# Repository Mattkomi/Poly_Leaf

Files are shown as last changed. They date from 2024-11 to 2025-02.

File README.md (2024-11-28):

# Poly_Leaf
PFE 2024-2025 Polytech SIR, projet Visio
Ce projet vise à développer un système de Stream Deck permettant de centraliser et d'optimiser la gestion des équipements situés dans des salles spécifiques. 
L'objectif est de créer un dispositif ergonomique et intuitif regroupant toutes les connexions HDMI, RJ45, et USB des différents équipements dans un système unifié, 
tout en offrant des fonctionnalités avancées comme la création de macros personnalisées.

Le système est conçu pour :

Simplifier la gestion des équipements grâce à une interface centralisée.
Automatiser des tâches fréquentes, comme l'affichage des participants sur l'écran de retour ou le lancement d'applications utilisées régulièrement.
Reproduire, tout en innovant, les fonctionnalités de l'interface StarLeaf.
Ce projet a été réalisé dans le cadre du PFE VISIO de la filière Polytech SIR par :

Vincent Goossens
Matthieu Komisarek

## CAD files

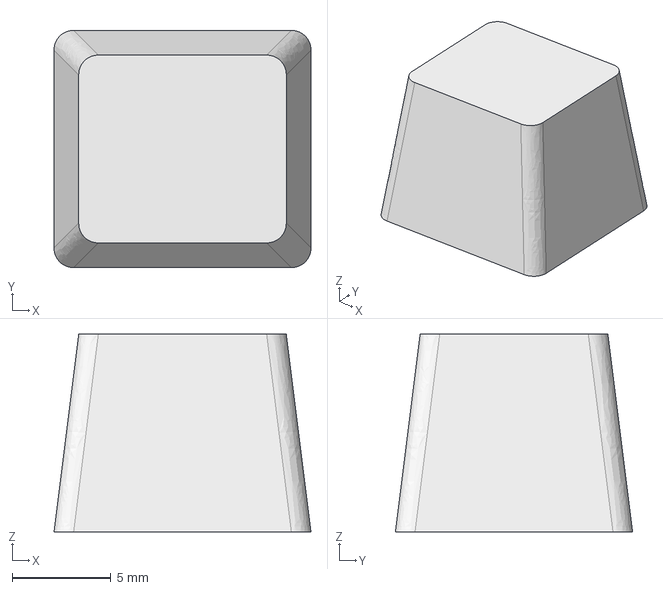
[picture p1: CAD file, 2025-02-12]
CAO/Capuchon.step
13.0 x 12.0 x 10.0 mm

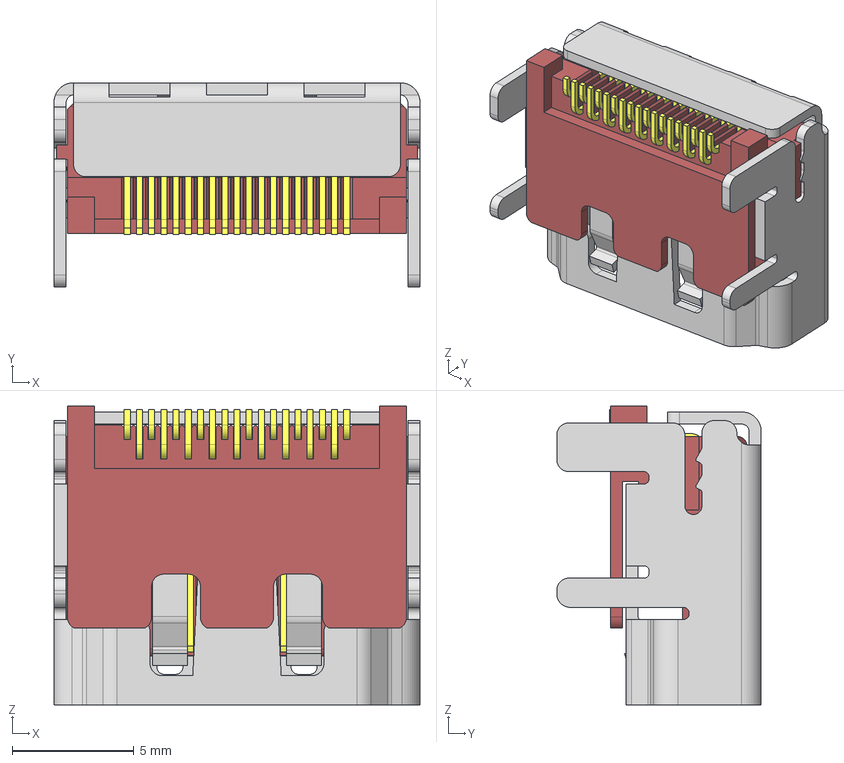
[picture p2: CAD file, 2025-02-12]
PCB_controleur/CAO/HDMR-19-01-S-SM-TR.step
15.0 x 8.38 x 12.2 mm
HDMR-19-01-S-SM-TR_b
HDMR-19-01-S-SM-TR_s
HDMR-19-01-S-SM-TR_p

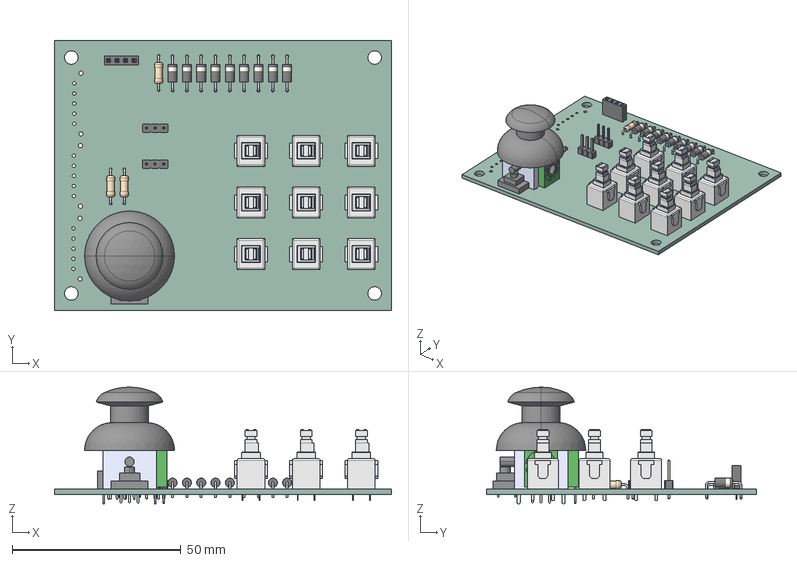
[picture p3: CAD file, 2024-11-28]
PCB_panel/CAO/PCB_panel.step
100.0 x 80.0 x 34.7 mm
D_A-405_P10.16mm_Horizontal x 9
COM-09032
PinHeader_1x03_P254mm_Vertical x 2
PinSocket_1x04_P254mm_Vertical
R_Axial_DIN0207_L63mm_D25mm_P1016mm_Horizontal x 3
PCB_panel PCB

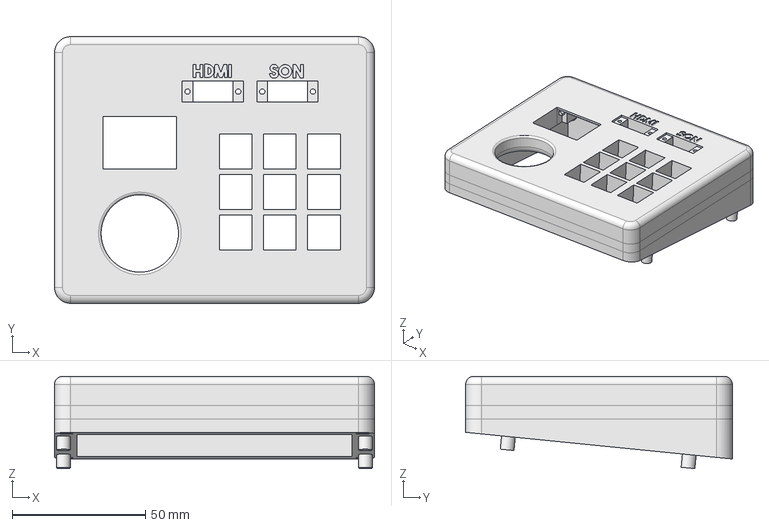
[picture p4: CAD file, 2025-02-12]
CAO/Haut.step
120.0 x 100.0 x 34.6 mm

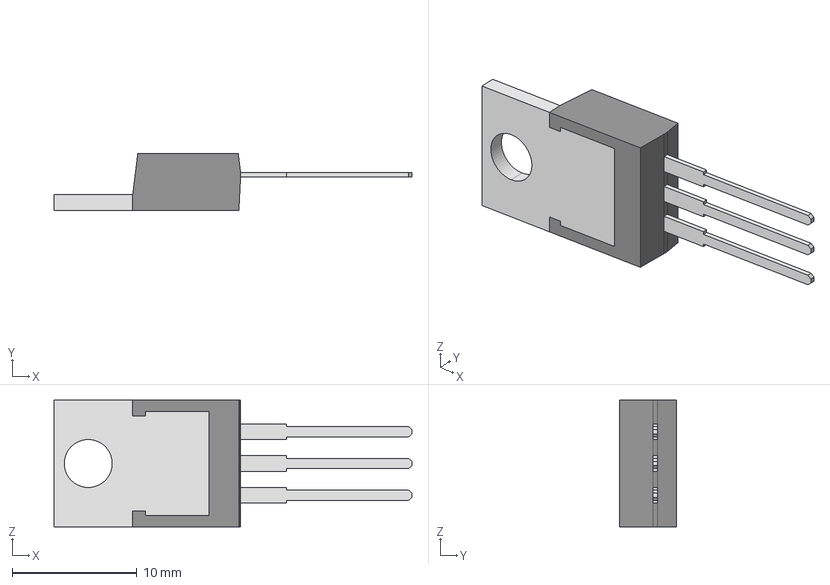
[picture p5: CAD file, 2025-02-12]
PCB_controleur/CAO/NDE0003B.stp
28.7 x 4.57 x 10.2 mm
T03B_BODY
T03B_LEAD x 3
T03B_HS

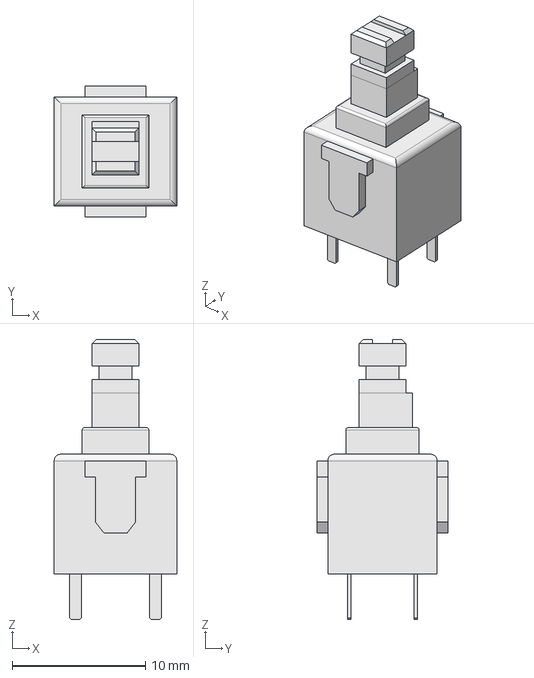
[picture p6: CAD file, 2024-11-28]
PCB_panel/CAO/ToucheF-Body.step
9.20 x 9.80 x 21.0 mm

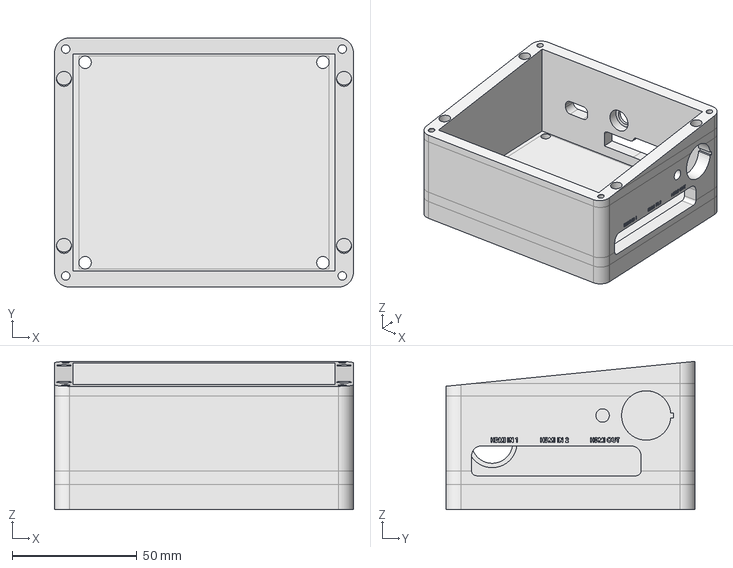
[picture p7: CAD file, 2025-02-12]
CAO/Bas.step
120.0 x 100.0 x 59.5 mm

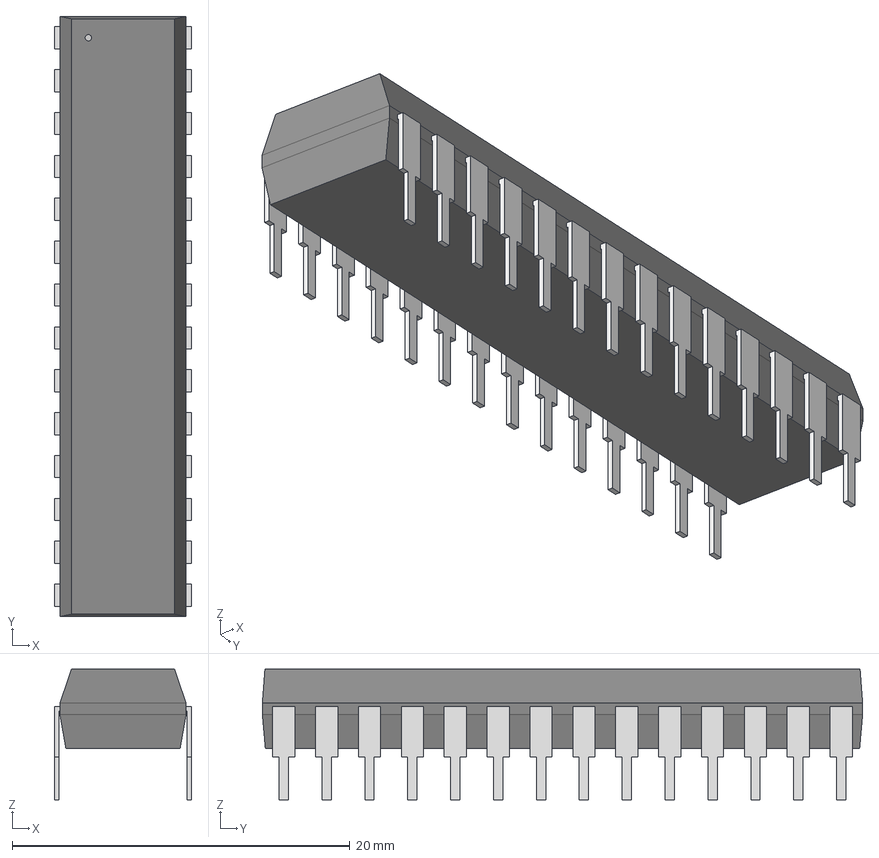
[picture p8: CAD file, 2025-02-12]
PCB_controleur/CAO/SPDIP28_300MC_MCH.step
8.12 x 35.6 x 7.75 mm

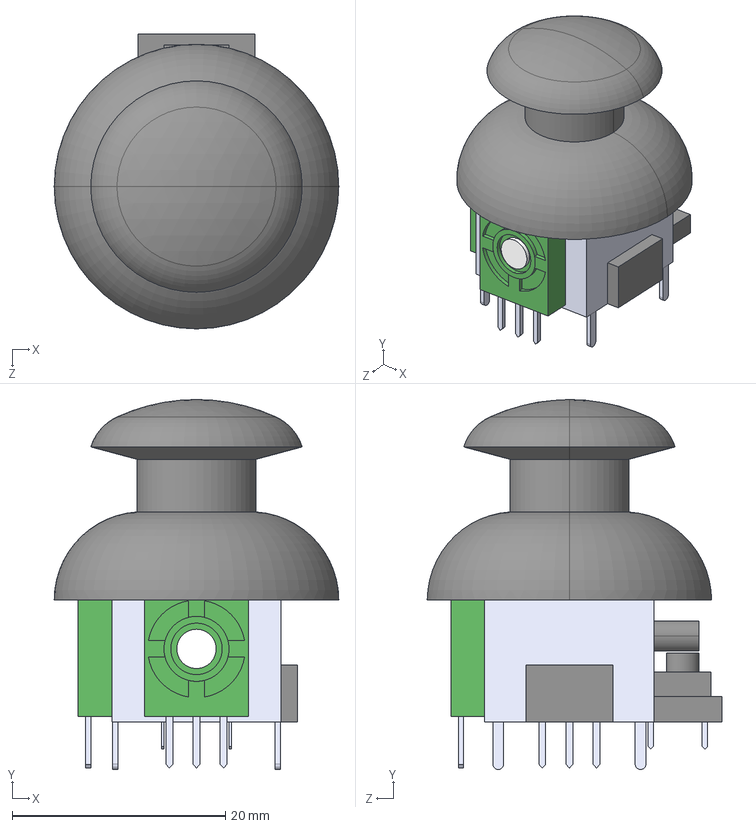
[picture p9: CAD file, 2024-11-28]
PCB_panel/CAO/COM-09032.step
26.7 x 34.7 x 27.6 mm

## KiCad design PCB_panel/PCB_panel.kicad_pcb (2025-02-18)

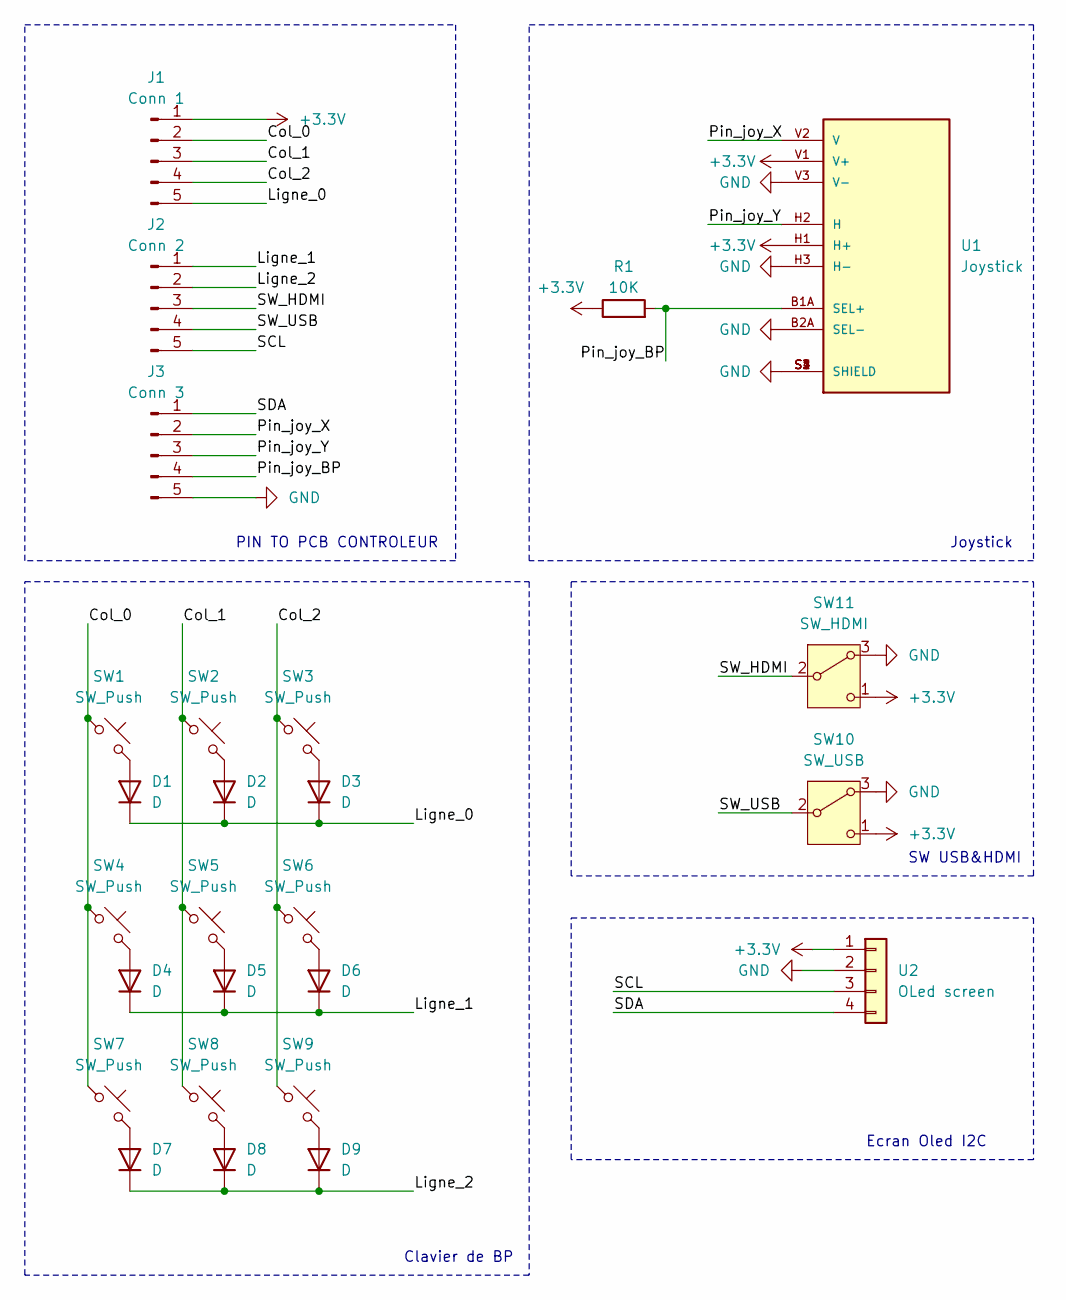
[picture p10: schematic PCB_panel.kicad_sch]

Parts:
D1, D2, D3, D4, D5, D6, D7, D8, D9: D; D_A-405_P10.16mm_Horizontal
J1: Conn 1; Molex_Micro-Fit_3.0_43650-0515_1x05_P3.00mm_Vertical
J2: Conn 2; Molex_Micro-Fit_3.0_43650-0515_1x05_P3.00mm_Vertical
J3: Conn 3; Molex_Micro-Fit_3.0_43650-0515_1x05_P3.00mm_Vertical
R1: 10K; R_Axial_DIN0207_L6.3mm_D2.5mm_P10.16mm_Horizontal
SW1, SW2, SW3, SW4, SW5, SW6, SW7, SW8, SW9: SW_Push; PVA1 OA H1 1.2N V2
SW10: SW_USB; PinHeader_1x03_P2.54mm_Vertical
SW11: SW_HDMI; PinHeader_1x03_P2.54mm_Vertical
U1: Joystick; XDCR_COM-09032; PARTREV N/A
U2: OLed screen; PinSocket_1x04_P2.54mm_Vertical

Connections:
+3.3V: J1.1, R1.1, SW10.1 (C), SW11.1 (C), U1.H1 (H+), U1.V1 (V+), U2.1
/Col_0: J1.2, SW1.1, SW4.1, SW7.1
/Col_1: J1.3, SW2.1, SW5.1, SW8.1
/Col_2: J1.4, SW3.1, SW6.1, SW9.1
/Ligne_0: D1.1 (K), D2.1 (K), D3.1 (K), J1.5
/Ligne_1: D4.1 (K), D5.1 (K), D6.1 (K), J2.1
/Ligne_2: D7.1 (K), D8.1 (K), D9.1 (K), J2.2
/Pin_joy_BP: J3.4, R1.2, U1.B1A (SEL+)
/Pin_joy_X: J3.2, U1.V2 (V)
/Pin_joy_Y: J3.3, U1.H2 (H)
/SCL: J2.5, U2.3
/SDA: J3.1, U2.4
/SW_HDMI: J2.3, SW11.2 (B)
/SW_USB: J2.4, SW10.2 (B)
GND: J3.5, SW10.3 (A), SW11.3 (A), U1.B2A (SEL-), U1.H3 (H-), U1.S1 (SHIELD), U1.S2 (SHIELD), U1.S3 (SHIELD), U1.S4 (SHIELD), U1.V3 (V-), U2.2
unnamed: D1.2 (A), SW1.2
unnamed: D2.2 (A), SW2.2
unnamed: D3.2 (A), SW3.2
unnamed: D4.2 (A), SW4.2
unnamed: D5.2 (A), SW5.2
unnamed: D6.2 (A), SW6.2
unnamed: D7.2 (A), SW7.2
unnamed: D8.2 (A), SW8.2
unnamed: D9.2 (A), SW9.2

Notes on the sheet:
Ecran Oled I2C
SW USB&HDMI
Joystick
PIN TO PCB CONTROLEUR
Clavier de BP

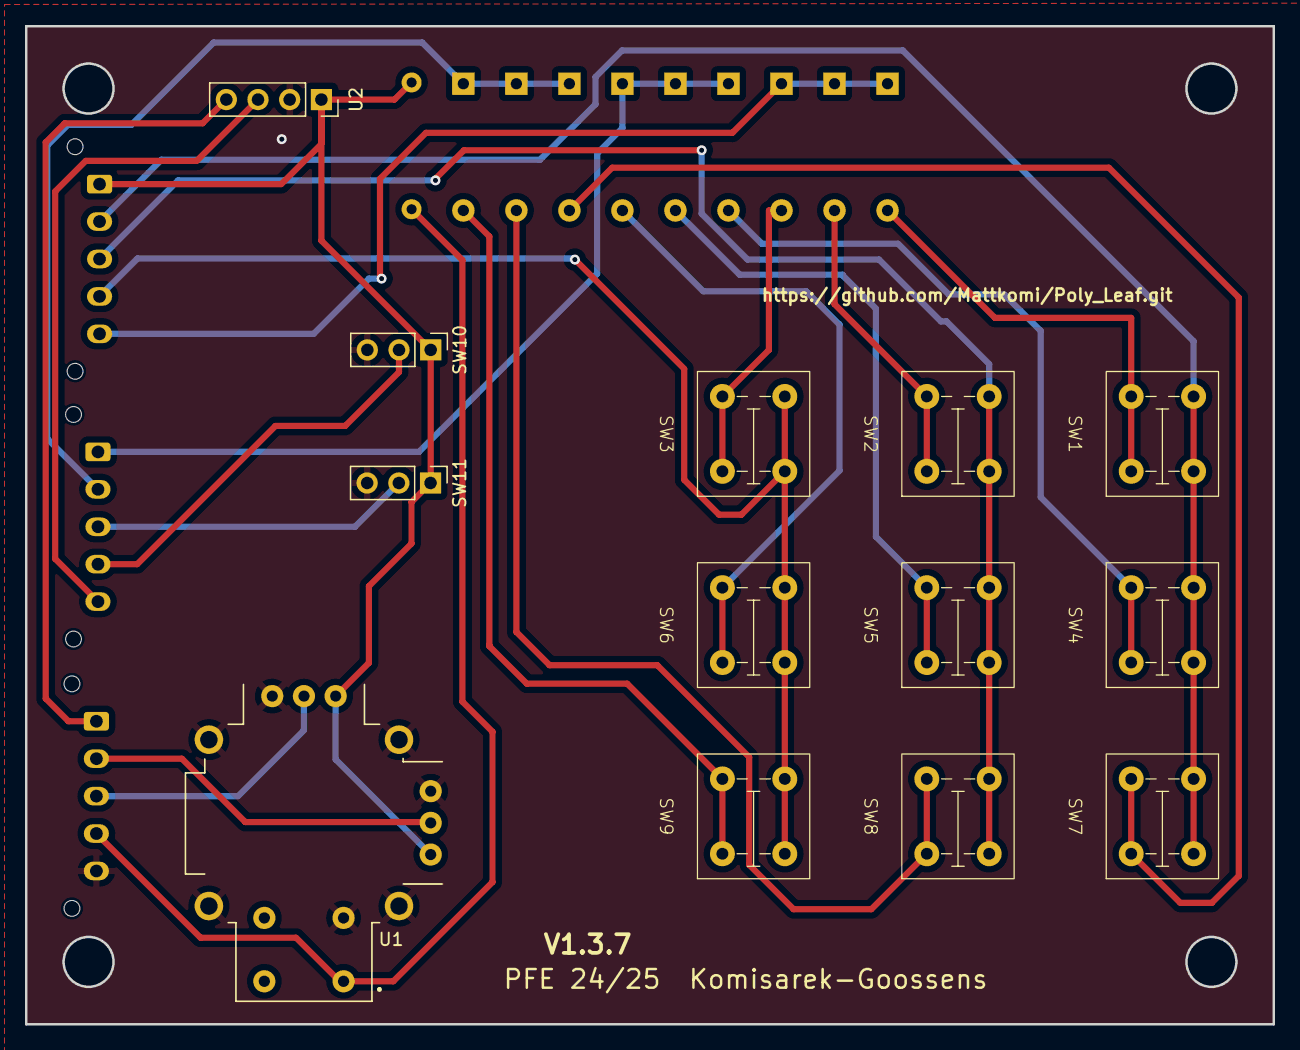
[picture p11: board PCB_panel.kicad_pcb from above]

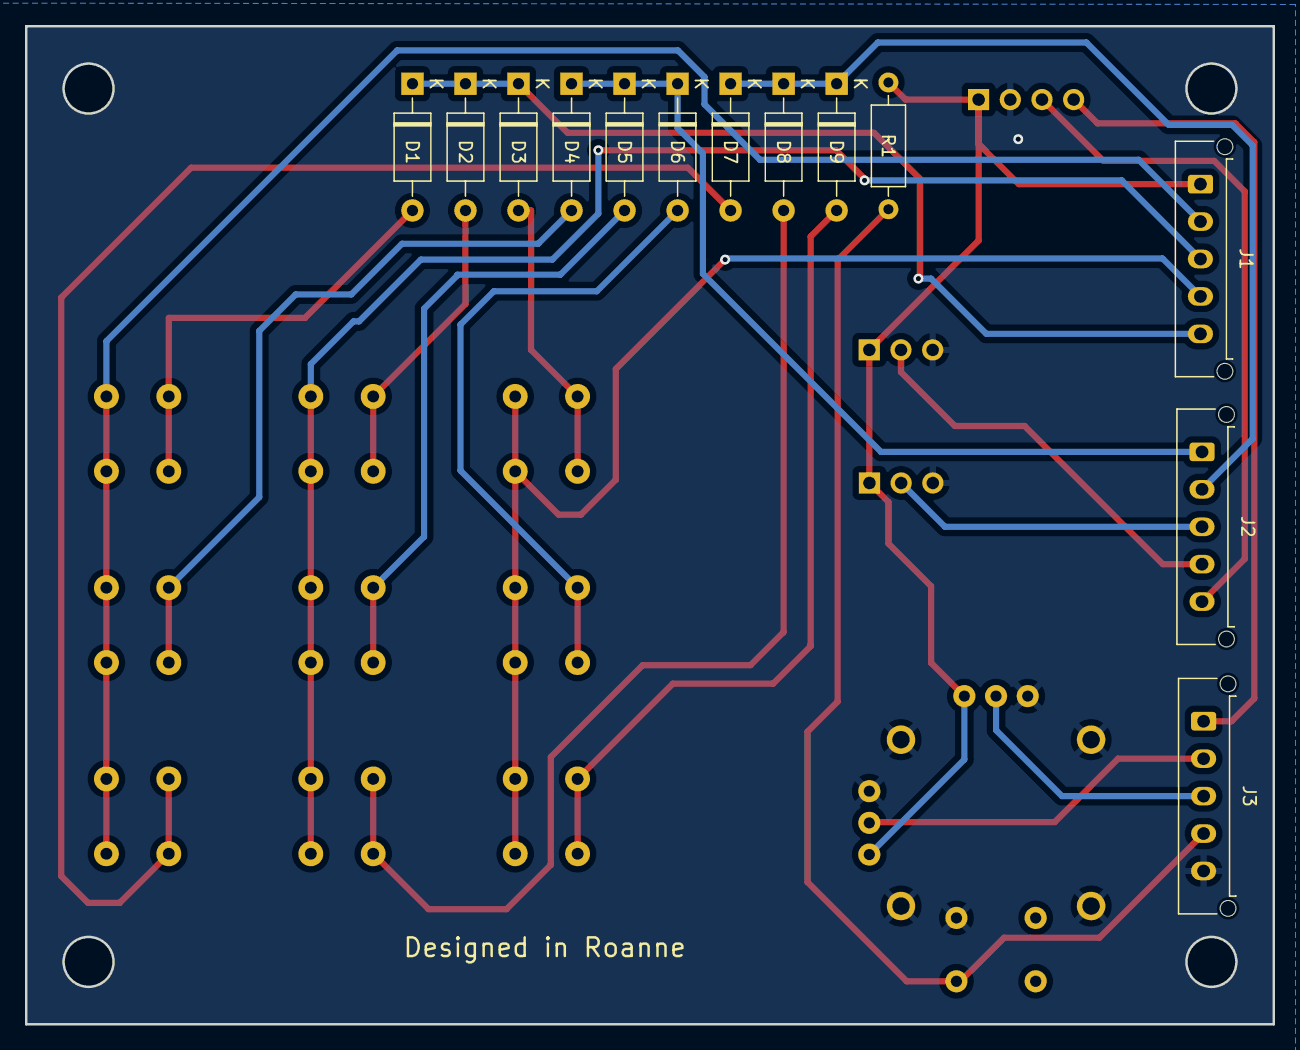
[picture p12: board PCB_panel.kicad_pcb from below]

Board: 2 copper layers, 100.0 x 80.0 mm, 26 parts (13 on the bottom side), 24 nets.

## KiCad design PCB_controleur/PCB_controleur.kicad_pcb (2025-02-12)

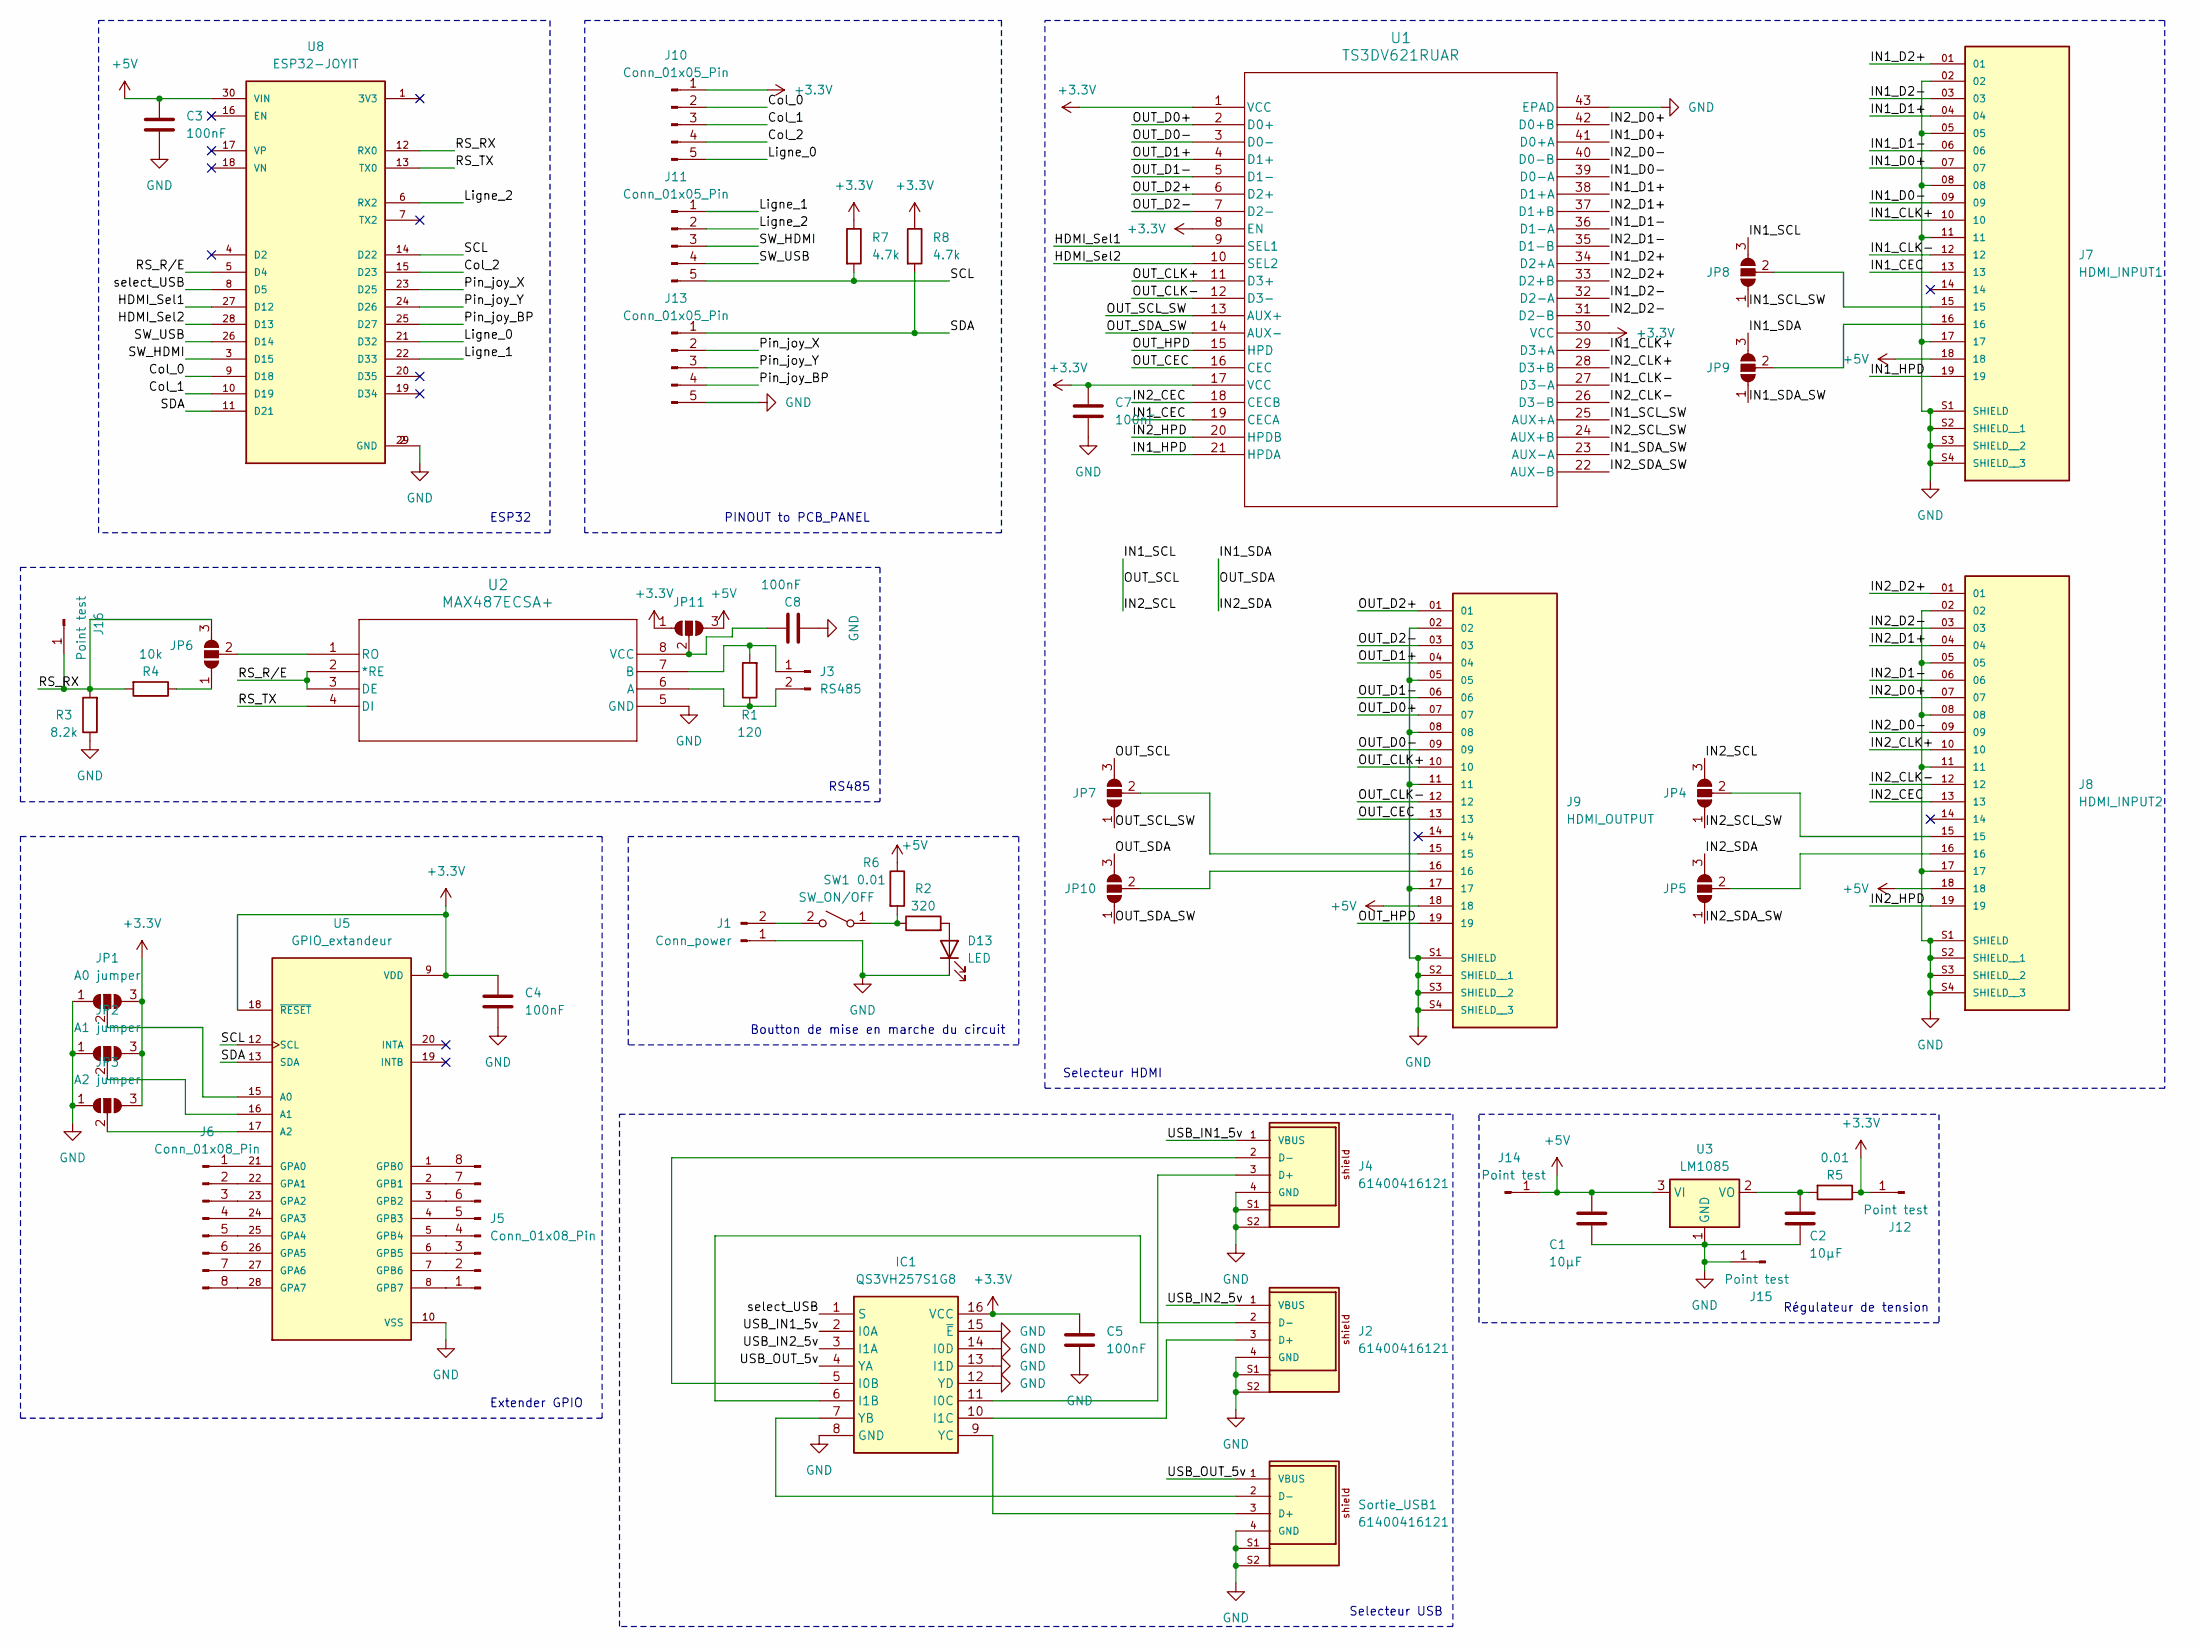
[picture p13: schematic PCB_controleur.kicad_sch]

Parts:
C1, C2: 10µF; CP_Radial_D5.0mm_P2.50mm
C3, C4, C5, C7, C8: 100nF; CAPC2012X135N
D13: LED; LED_D5.0mm
IC1: QS3VH257S1G8; SOIC127P600X175-16N; Manufacturer_Part_Number QS3VH257S1G8
J1: Conn_power; TerminalBlock_bornier-2_P5.08mm
J2, J4: 61400416121; PART-NUMBER 61400416121
J3: RS485; TerminalBlock_bornier-2_P5.08mm
J5, J6: Conn_01x08_Pin; PinHeader_1x08_P2.54mm_Vertical
J7: HDMI_INPUT1; SAMTEC_HDMR-19-01-S-SM-TR; PARTREV H
J8: HDMI_INPUT2; SAMTEC_HDMR-19-01-S-SM-TR; PARTREV H
J9: HDMI_OUTPUT; SAMTEC_HDMR-19-01-S-SM-TR; PARTREV H
J10, J11, J13: Conn_01x05_Pin; Molex_Micro-Fit_3.0_43650-0515_1x05_P3.00mm_Vertical
J12, J14, J15, J16: Point test; PinHeader_1x01_P2.00mm_Vertical
JP1: A0 jumper; SolderJumper-3_P1.3mm_Open_Pad1.0x1.5mm
JP2: A1 jumper; SolderJumper-3_P1.3mm_Open_Pad1.0x1.5mm
JP3: A2 jumper; SolderJumper-3_P1.3mm_Open_Pad1.0x1.5mm
JP4, JP5, JP6, JP7, JP8, JP9, JP10, JP11: SolderJumper_3_Open; SolderJumper-3_P1.3mm_Open_RoundedPad1.0x1.5mm_NumberLabels
R1: 120; R_Axial_DIN0207_L6.3mm_D2.5mm_P10.16mm_Horizontal
R2: 320; R_Axial_DIN0207_L6.3mm_D2.5mm_P10.16mm_Horizontal
R3: 8.2k; R_Axial_DIN0207_L6.3mm_D2.5mm_P10.16mm_Horizontal
R4: 10k; R_Axial_DIN0207_L6.3mm_D2.5mm_P10.16mm_Horizontal
R5, R6: 0.01; WSHM28181L000FEA
R7, R8: 4.7k; R_Axial_DIN0207_L6.3mm_D2.5mm_P10.16mm_Horizontal
SW1: SW_ON/OFF; JST_EH_B2B-EH-A_1x02_P2.50mm_Vertical
Sortie_USB1: 61400416121; 62900416021; PART-NUMBER 61400416121
U1: TS3DV621RUAR; RUA42_7P55X2P05_TEX
U2: MAX487ECSA+; 21-0041B_8_MXM
U3: LM1085; TO-220-3_Vertical
U5: GPIO_extandeur; SPDIP28_300MC_MCH; PARTREV C
U8: ESP32-JOYIT; MODULE_ESP32_DEVKIT_JOYIT; PARTREV N/A

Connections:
+3.3V: C4.1, C5.1, C7.1, IC1.16 (VCC), J10.1, J12.1, JP1.3 (B), JP2.3 (B), JP3.3 (B), JP11.1 (A), R5.1, R7.1, R8.1, U1.1 (VCC), U1.8 (EN), U1.17 (VCC), U1.30 (VCC), U5.9 (VDD), U5.18 (~RESET)
+5V: C1.1, C3.1, J7.18, J8.18, J9.18, J14.1, JP11.3 (B), R6.1, U3.3 (VI), U8.30 (VIN)
/Col_0: J10.2, U8.9 (D18)
/Col_1: J10.3, U8.10 (D19)
/Col_2: J10.4, U8.15 (D23)
/HDMI_Sel1: U1.9 (SEL1), U8.27 (D12)
/HDMI_Sel2: U1.10 (SEL2), U8.28 (D13)
/IN1_CEC: J7.13, U1.19 (CECA)
/IN1_CLK+: J7.10, U1.29 (D3+A)
/IN1_CLK-: J7.12, U1.27 (D3-A)
/IN1_D0+: J7.07, U1.41 (D0+A)
/IN1_D0-: J7.09, U1.39 (D0-A)
/IN1_D1+: J7.04, U1.38 (D1+A)
/IN1_D1-: J7.06, U1.36 (D1-A)
/IN1_D2+: J7.01, U1.34 (D2+A)
/IN1_D2-: J7.03, U1.32 (D2-A)
/IN1_HPD: J7.19, U1.21 (HPDA)
/IN1_SCL: JP4.3 (B), JP7.3 (B), JP8.3 (B)
/IN1_SCL_SW: JP8.1 (A), U1.25 (AUX+A)
/IN1_SDA: JP5.3 (B), JP9.3 (B), JP10.3 (B)
/IN1_SDA_SW: JP9.1 (A), U1.23 (AUX-A)
/IN2_CEC: J8.13, U1.18 (CECB)
/IN2_CLK+: J8.10, U1.28 (D3+B)
/IN2_CLK-: J8.12, U1.26 (D3-B)
/IN2_D0+: J8.07, U1.42 (D0+B)
/IN2_D0-: J8.09, U1.40 (D0-B)
/IN2_D1+: J8.04, U1.37 (D1+B)
/IN2_D1-: J8.06, U1.35 (D1-B)
/IN2_D2+: J8.01, U1.33 (D2+B)
/IN2_D2-: J8.03, U1.31 (D2-B)
/IN2_HPD: J8.19, U1.20 (HPDB)
/IN2_SCL_SW: JP4.1 (A), U1.24 (AUX+B)
/IN2_SDA_SW: JP5.1 (A), U1.22 (AUX-B)
/Ligne_0: J10.5, U8.21 (D32)
/Ligne_1: J11.1, U8.22 (D33)
/Ligne_2: J11.2, U8.6 (RX2)
/OUT_CEC: J9.13, U1.16 (CEC)
/OUT_CLK+: J9.10, U1.11 (D3+)
/OUT_CLK-: J9.12, U1.12 (D3-)
/OUT_D0+: J9.07, U1.2 (D0+)
/OUT_D0-: J9.09, U1.3 (D0-)
/OUT_D1+: J9.04, U1.4 (D1+)
/OUT_D1-: J9.06, U1.5 (D1-)
/OUT_D2+: J9.01, U1.6 (D2+)
/OUT_D2-: J9.03, U1.7 (D2-)
/OUT_HPD: J9.19, U1.15 (HPD)
/OUT_SCL_SW: JP7.1 (A), U1.13 (AUX+)
/OUT_SDA_SW: JP10.1 (A), U1.14 (AUX-)
/Pin_joy_BP: J13.4, U8.25 (D27)
/Pin_joy_X: J13.2, U8.23 (D25)
/Pin_joy_Y: J13.3, U8.24 (D26)
/RS_RX: J16.1, JP6.3 (B), R3.2, R4.2, U8.12 (RX0)
/RS_R/E: U2.2 (*RE), U2.3 (DE), U8.5 (D4)
/RS_TX: U2.4 (DI), U8.13 (TX0)
/SCL: J11.5, R7.2, U5.12 (SCL), U8.14 (D22)
/SDA: J13.1, R8.2, U5.13 (SDA), U8.11 (D21)
/SW_HDMI: J11.3, U8.3 (D15)
/SW_USB: J11.4, U8.26 (D14)
/USB_IN1_5v: IC1.2 (I0A), J4.1 (VBUS)
/USB_IN2_5v: IC1.3 (I1A), J2.1 (VBUS)
/USB_OUT_5v: IC1.4 (YA), Sortie_USB1.1 (VBUS)
/select_USB: IC1.1 (S), U8.8 (D5)
GND: C1.2, C2.2, C3.2, C4.2, C5.2, C7.2, C8.2, D13.1 (K), IC1.8 (GND), IC1.12 (YD), IC1.13 (I1D), IC1.14 (I0D), IC1.15 (~E), J1.1, J2.4 (GND), J2.S1, J2.S2, J4.4 (GND), J4.S1, J4.S2, J7.02, J7.05, J7.08, J7.11, J7.17, J7.S1 (SHIELD), J7.S2 (SHIELD__1), J7.S3 (SHIELD__2), J7.S4 (SHIELD__3), J8.02, J8.05, J8.08, J8.11, J8.17, J8.S1 (SHIELD), J8.S2 (SHIELD__1), J8.S3 (SHIELD__2), J8.S4 (SHIELD__3), J9.02, J9.05, J9.08, J9.11, J9.17, J9.S1 (SHIELD), J9.S2 (SHIELD__1), J9.S3 (SHIELD__2), J9.S4 (SHIELD__3), J13.5, J15.1, JP1.1 (A), JP2.1 (A), JP3.1 (A), R3.1, Sortie_USB1.4 (GND), Sortie_USB1.S1, Sortie_USB1.S2, U1.43 (EPAD), U2.5 (GND), U3.1 (GND), U5.10 (VSS), U8.2 (GND), U8.29 (GND)
unnamed: D13.2 (A), R2.2
unnamed: IC1.5 (I0B), J4.2 (D-)
unnamed: IC1.11 (I0C), J4.3 (D+)
unnamed: IC1.6 (I1B), J2.2 (D-)
unnamed: IC1.10 (I1C), J2.3 (D+)
unnamed: IC1.7 (YB), Sortie_USB1.2 (D-)
unnamed: IC1.9 (YC), Sortie_USB1.3 (D+)
unnamed: J1.2, SW1.2 (B)
unnamed: J3.1, R1.2, U2.7 (B)
unnamed: J3.2, R1.1, U2.6 (A)
unnamed: J5.1, U5.8 (GPB7)
unnamed: J5.2, U5.7 (GPB6)
unnamed: J5.3, U5.6 (GPB5)
unnamed: J5.4, U5.5 (GPB4)
unnamed: J5.5, U5.4 (GPB3)
unnamed: J5.6, U5.3 (GPB2)
unnamed: J5.7, U5.2 (GPB1)
unnamed: J5.8, U5.1 (GPB0)
unnamed: J6.1, U5.21 (GPA0)
unnamed: J6.2, U5.22 (GPA1)
unnamed: J6.3, U5.23 (GPA2)
unnamed: J6.4, U5.24 (GPA3)
unnamed: J6.5, U5.25 (GPA4)
unnamed: J6.6, U5.26 (GPA5)
unnamed: J6.7, U5.27 (GPA6)
unnamed: J6.8, U5.28 (GPA7)
unnamed: JP1.2 (C), U5.15 (A0)
unnamed: JP2.2 (C), U5.16 (A1)
unnamed: JP3.2 (C), U5.17 (A2)
unnamed: J8.15, JP4.2 (C)
unnamed: J8.16, JP5.2 (C)
unnamed: JP6.1 (A), R4.1
unnamed: JP6.2 (C), U2.1 (RO)
unnamed: J9.15, JP7.2 (C)
unnamed: J7.15, JP8.2 (C)
unnamed: J7.16, JP9.2 (C)
unnamed: J9.16, JP10.2 (C)
unnamed: C8.1, JP11.2 (C), U2.8 (VCC)
unnamed: R2.1, R6.2, SW1.1 (A)
unnamed: C2.1, R5.2, U3.2 (VO)

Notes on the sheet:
RS485
PINOUT to PCB_PANEL
Selecteur USB
Extender GPIO
ESP32
Selecteur HDMI
Régulateur de tension
Boutton de mise en marche du circuit

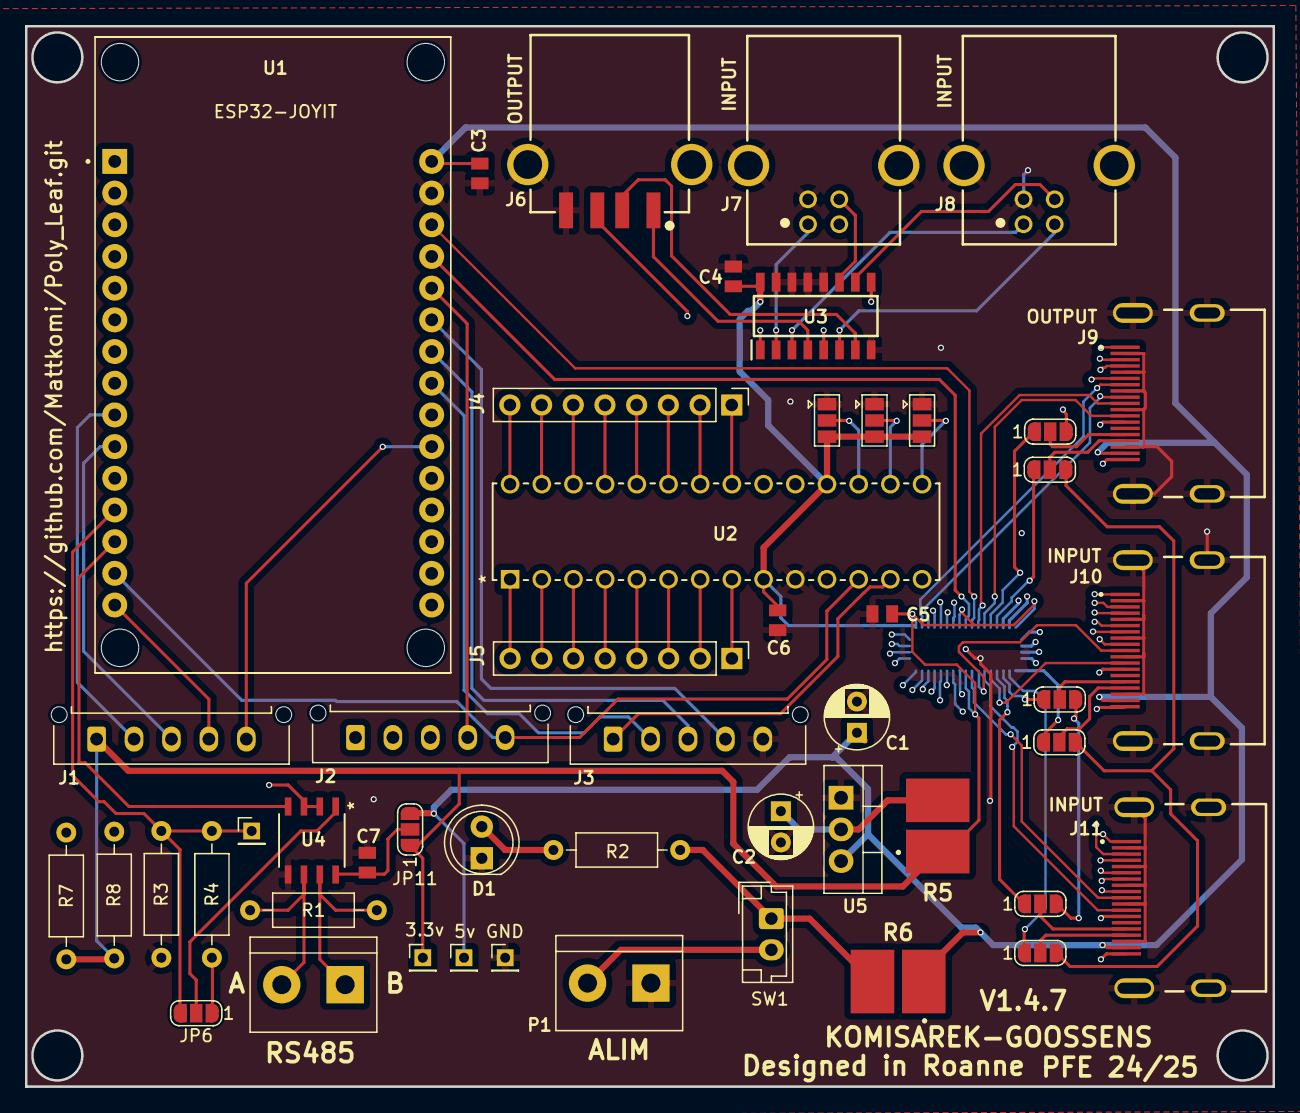
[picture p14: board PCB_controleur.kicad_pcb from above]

Board: 4 copper layers, 100.0 x 85.0 mm, 51 parts (1 on the bottom side), 103 nets.

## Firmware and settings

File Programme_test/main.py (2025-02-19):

from machine import Pin, ADC, UART, SoftI2C
import ssd1306
import time

# ======================== Définition des broches ========================= #
TX_PIN = 1  # Broche TX pour communication série
SELECTOR_PIN = Pin(4, Pin.OUT)  # Sélection lecture/écriture

# Joystick
axeX = ADC(Pin(26))  # Axe X joystick
axeY = ADC(Pin(25))  # Axe Y joystick
joystick_button = Pin(27, Pin.IN, Pin.PULL_UP)  # Bouton joystick

# Matrice de boutons (zoom)
rows = [Pin(32, Pin.IN, Pin.PULL_DOWN), Pin(33, Pin.IN, Pin.PULL_DOWN), Pin(16, Pin.IN, Pin.PULL_DOWN)]
cols = [Pin(18, Pin.OUT), Pin(19, Pin.OUT), Pin(23, Pin.OUT)]
for col in cols:
    col.value(0)

# Switch HDMI/USB
switch_son = Pin(14, Pin.IN)
output_son = Pin(5, Pin.OUT)
switch_hdmi = Pin(15, Pin.IN)
hdmi_pin1 = Pin(12, Pin.OUT)
hdmi_pin2 = Pin(13, Pin.OUT)

# OLED configuration
i2c = SoftI2C(scl=Pin(22), sda=Pin(21))
oled = ssd1306.SSD1306_I2C(128, 64, i2c)

# Communication série
mySerial = UART(1, baudrate=9600, tx=Pin(TX_PIN))

# ======================== Commandes VISCA =============================== #
VISCA_BROADCAST_up = bytearray([0x81, 0x01, 0x06, 0x01, 0x0C, 0x0A, 0x03, 0x01, 0xFF])
VISCA_BROADCAST_down = bytearray([0x81, 0x01, 0x06, 0x01, 0x0C, 0x0A, 0x03, 0x02, 0xFF])
VISCA_BROADCAST_left = bytearray([0x81, 0x01, 0x06, 0x01, 0x0C, 0x0A, 0x01, 0x03, 0xFF])
VISCA_BROADCAST_right = bytearray([0x81, 0x01, 0x06, 0x01, 0x0C, 0x0A, 0x02, 0x03, 0xFF])
VISCA_BROADCAST_stop = bytearray([0x81, 0x01, 0x06, 0x01, 0x00, 0x00, 0x03, 0x03, 0xFF])
VISCA_BROADCAST_zoomIn = bytearray([0x81, 0x01, 0x04, 0x07, 0x02, 0xFF])
VISCA_BROADCAST_zoomOut = bytearray([0x81, 0x01, 0x04, 0x07, 0x03, 0xFF])
VISCA_BROADCAST_zoomOff = bytearray([0x81, 0x01, 0x04, 0x07, 0x00, 0xFF])
VISCA_BROADCAST_upleft = bytearray([0x81, 0x01, 0x06, 0x01, 0x0C, 0x0A, 0x02, 0x02, 0xFF])
VISCA_BROADCAST_upright = bytearray([0x81, 0x01, 0x06, 0x01, 0x0C, 0x0A, 0x01, 0x02, 0xFF])
VISCA_BROADCAST_downleft = bytearray([0x81, 0x01, 0x06, 0x01, 0x0C, 0x0A, 0x02, 0x01, 0xFF])
VISCA_BROADCAST_downright = bytearray([0x81, 0x01, 0x06, 0x01, 0x0C, 0x0A, 0x01, 0x01, 0xFF])

VISCA_BROADCAST_brightIn = bytearray([0x81, 0x01, 0x04, 0x0D, 0x02, 0xFF])
VISCA_BROADCAST_brightOut = bytearray([0x81, 0x01, 0x04, 0x0D, 0x03, 0xFF])
VISCA_BROADCAST_gainIn = bytearray([0x81, 0x01, 0x04, 0x0C, 0x02, 0xFF])
VISCA_BROADCAST_gainOut = bytearray([0x81, 0x01, 0x04, 0x0C, 0x03, 0xFF])
VISCA_BROADCAST_freezeIn = bytearray([0x81, 0x01, 0x04, 0x62, 0x02, 0xFF])
VISCA_BROADCAST_freezeOut = bytearray([0x81, 0x01, 0x04, 0x62, 0x03, 0xFF])
VISCA_BROADCAST_setHome = bytearray([0x81, 0x01, 0x06, 0x04,0xFF])



# ======================== Variables globales ============================ #
lastMovementTime = 0
cameraActive = True
isMoving = False
joystickNeutralX = 2048
joystickNeutralY = 2048
threshold = 500
timeoutDuration = 5000  # Timeout in ms
zooming = False  # État actuel du zoom
brighting = False # État actuel du focus
freezing = False
gaining = False

# ======================== Fonctions utilitaires ========================= #
def sendVISCACommand(command):
    SELECTOR_PIN.value(1)
    time.sleep(0.01)
    mySerial.write(command)
    mySerial.flush()
    time.sleep(0.01)
    SELECTOR_PIN.value(0)

def check_son():
    state_son = switch_son.value()
    output_son.value(state_son)
    return state_son

def check_hdmi():
    state_hdmi = switch_hdmi.value()
    hdmi_pin1.value(state_hdmi)
    hdmi_pin2.value(state_hdmi)
    return state_hdmi

def display_oled(son_state, hdmi_state, joystick_status, zoom_status, brightness_status):
    oled.fill(0)
    oled.text("Switch Test", 0, 0)
    oled.text(f"SON: {'Prof' if son_state else 'EXT'}", 0, 20)
    oled.text(f"HDMI: {'PROF' if hdmi_state else 'EXT'}", 0, 30)
    oled.text(f"Joystick: {joystick_status}", 0, 40)
    oled.text(f"Zoom: {zoom_status}", 0, 50)
    oled.text(f"Zoom: {brightness_status}", 0, 60)
    oled.show()

def scan_matrix():
    """Scanne la matrice et retourne les boutons pressés sous forme de liste (ligne, colonne)."""
    pressed_buttons = []
    for j, col in enumerate(cols):
        # Activer une colonne à la fois
        col.value(1)
        for i, row in enumerate(rows):
            if row.value() == 1:  # Si le bouton est pressé
                pressed_buttons.append((i, j))  # Ajouter la position (ligne, colonne)
        col.value(0)  # Désactiver la colonne
    return pressed_buttons

# ======================== Programme principal =========================== #
def main():
    global lastMovementTime, cameraActive, isMoving, zooming, brighting, gaining

    axeX.atten(ADC.ATTN_11DB)
    axeY.atten(ADC.ATTN_11DB)

    while True:
        # Lecture du joystick
        valX = axeX.read()
        valY = axeY.read()
        btnJoystick = joystick_button.value()

        # Lecture des boutons pour le zoom via la matrice
        buttons = scan_matrix()
        zoomIn = any(button == (0, 1) for button in buttons)  # Si le premier bouton est pressé
        zoomOut = any(button == (0, 0) for button in buttons)  # Si le deuxième bouton est pressé
        gainIn= any(button == (1, 2) for button in buttons)  
        gainOut= any(button == (1, 1) for button in buttons)
        setHome = any(button == (1, 0) for button in buttons)
        #setTableau = any(button == (2, 2) for button in buttons)
        #freeze = any(button == (2, 2) for button in buttons)
        brightIn = any(button == (2, 2) for button in buttons)
        brightOut = any(button == (2, 1) for button in buttons)

        # Lecture des switches
        son_state = check_son()
        hdmi_state = check_hdmi()

        # Gestion zoom
        if zoomIn and not zooming:
            sendVISCACommand(VISCA_BROADCAST_zoomIn)
            zooming = True
        elif zoomOut and not zooming:
            sendVISCACommand(VISCA_BROADCAST_zoomOut)
            zooming = True
        elif not zoomIn and not zoomOut and zooming:
            sendVISCACommand(VISCA_BROADCAST_zoomOff)
            zooming = False
        
        #Gestion Brightness
        if brightIn and not brighting :
            sendVISCACommand(VISCA_BROADCAST_brightIn)
            brighting = True
        elif brightOut and not brighting :
            sendVISCACommand(VISCA_BROADCAST_brightOut)
            brighting = True
        elif not brightIn and not brightOut and brighting:
            brighting = False
        
        #Gestion Brightness
        if gainIn and not gaining :
            sendVISCACommand(VISCA_BROADCAST_gainIn)
            gaining = True
        elif gainOut and not gaining :
            sendVISCACommand(VISCA_BROADCAST_gainOut)
            gaining = True
        elif not gainIn and not gainOut and gaining:
            gaining = False
            
        #Gestion setHome
        if setHome :
            sendVISCACommand(VISCA_BROADCAST_setHome)
            
        
        
            
        # Gestion caméra (mouvement)
        if btnJoystick == 0:
            cameraActive = True
            lastMovementTime = time.ticks_ms()

        if cameraActive:
            adjustedX = valX - joystickNeutralX
            adjustedY = valY - joystickNeutralY
            moved = False

            # Détection des mouvements diagonaux
            if adjustedX < -threshold and adjustedY < -threshold:
                sendVISCACommand(VISCA_BROADCAST_downright)
                moved = True
            elif adjustedX > threshold and adjustedY < -threshold:
                sendVISCACommand(VISCA_BROADCAST_downleft)
                moved = True
            elif adjustedX < -threshold and adjustedY > threshold:
                sendVISCACommand(VISCA_BROADCAST_upright)
                moved = True
            elif adjustedX > threshold and adjustedY > threshold:
                sendVISCACommand(VISCA_BROADCAST_upleft)
                moved = True
            elif adjustedX < -threshold:
                sendVISCACommand(VISCA_BROADCAST_left)
                moved = True
            elif adjustedX > threshold:
                sendVISCACommand(VISCA_BROADCAST_right)
                moved = True
            elif adjustedY < -threshold:
                sendVISCACommand(VISCA_BROADCAST_up)
                moved = True
            elif adjustedY > threshold:
                sendVISCACommand(VISCA_BROADCAST_down)
                moved = True

            # Arrêt si le joystick est neutre
            if not moved and isMoving:
                sendVISCACommand(VISCA_BROADCAST_stop)
                isMoving = False

            if moved:
                lastMovementTime = time.ticks_ms()
                isMoving = True

            if time.ticks_ms() - lastMovementTime > timeoutDuration:
                cameraActive = False
                sendVISCACommand(VISCA_BROADCAST_stop)

        # Mise à jour de l'affichage OLED
        joystick_status = "Active" if isMoving else "Inactive"
        zoom_status = "In" if zoomIn else "Out" if zoomOut else "Off"
        brightness_status = "+" if brightIn else "-" if brightOut else "Off"
        display_oled(son_state, hdmi_state, joystick_status, zoom_status,brightness_status)

        time.sleep(0.1)

# ======================== Exécution du programme ======================== #
if __name__ == "__main__":
    main()

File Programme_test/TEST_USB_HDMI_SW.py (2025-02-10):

from machine import Pin, SoftI2C
import ssd1306
from time import sleep

# Configuration des pins
switch_son = Pin(14, Pin.IN)  # Switch pour le son (pin 14)
output_son = Pin(5, Pin.OUT)  # Sortie pour le son (pin 5)
switch_externe = Pin(15, Pin.IN)  # Switch HDMI (pin 15)
hdmi_pin1 = Pin(12, Pin.OUT)  # HDMI pin 12
hdmi_pin2 = Pin(13, Pin.OUT)  # HDMI pin 13

# Configuration de l'I2C pour l'OLED
i2c = SoftI2C(scl=Pin(22), sda=Pin(21))
oled_width = 128
oled_height = 64
oled = ssd1306.SSD1306_I2C(oled_width, oled_height, i2c)

# Fonction pour vérifier l'état du switch son
def check_son():
    state_son = switch_son.value()  # Lecture de l'état du switch son (0 ou 1)
    output_son.value(state_son)  # Applique l'état du switch sur la sortie son
    return state_son

# Fonction pour configurer les pins HDMI en fonction du switch externe (pin 15)
def check_hdmi():
    switch_state = check_switch_externe()  # Lecture de l'état du switch externe
    hdmi_pin1.value(switch_state)  # Applique l'état du switch sur la pin HDMI 12
    hdmi_pin2.value(switch_state)  # Applique l'état du switch sur la pin HDMI 13

    return f"{switch_state}, {switch_state}"

# Fonction pour lire l'état du switch externe (pin 15)
def check_switch_externe():
    return switch_externe.value()  # Retourne l'état du switch externe (0 ou 1)

# Boucle principale pour afficher les résultats
while True:
    oled.fill(0)  # Efface l'écran

    # Lecture des états des switches
    son_state = check_son()
    hdmi_state = check_hdmi()
    switch_state = check_switch_externe()

    # Affichage des résultats
    oled.text("Switch Test", 0, 0)
    oled.text(f"SON: {'ON' if son_state else 'OFF'}", 0, 20)
    oled.text(f"Switch HDMI: {'ON' if switch_state else 'OFF'}", 0, 30)
    oled.text(f"HDMI: {hdmi_state}", 0, 40)
    oled.show()  # Mise à jour de l'écran

    print("Switch Test")
    print(f"SON: {'ON' if son_state else 'OFF'}")
    print(f"Switch HDMI: {'ON' if switch_state else 'OFF'}")
    print(f"HDMI: {hdmi_state}")

    sleep(0.5)  # Pause avant le prochain cycle

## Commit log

2024-11-28 Add .step pcb_panel
    [PCB_panel.step]
2024-11-28 Liste des composants V1.1.1
    [Liste des composants.xlsx]
2025-02-10 Programme de test
2025-02-12 Ajout du PCB Contrôleur
    [HDMR-19-01-S-SM-TR.step, NDE0003B.stp, PCB_controleur.kicad_pcb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]
2025-02-12 CAO du projet
    [Bas.step, Capuchon.step, Haut.step]
2025-02-18 update pcb
    [PCB_panel.kicad_pcb, PCB_panel.kicad_sch]

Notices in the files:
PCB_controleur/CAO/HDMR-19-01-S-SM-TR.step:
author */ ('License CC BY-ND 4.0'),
